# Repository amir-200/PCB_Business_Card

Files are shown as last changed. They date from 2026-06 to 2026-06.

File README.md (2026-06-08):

# PCB_Business_Card

## Final requirements 

1. LED Matrix
2. Battery powered
3. PCB Edge USB-C Connector (For programming/ act as MSC (mass storage class) device to update content)
4. MSC(Mass Storage Class) device so the content of the display can be updated easily
5. Fluid Simulation
6. RTC
7. NFC
8. Provision for interfacing an OLED display 

## Technical Specs

1. Double sided 2 layer PCB
2. 252 LEDs (Yellow/ White)
4. TM1640 LED drive controller IC x 2
5. PCB Edge USB-C Connector 
6. RP2350A MCU 
7. ST25TN01K NFC Forum Type 2 Tag IC
8. TP4057 Linear battery charger
9. QMI8658 IMU 
10. External Flash 
11. LIR2032 Coin cell
12. MOQ : 5

## TODO 

[ ] USB circuitry  : Mihir

[ ] battery charging : amir

[ ] Card Controller foundation: RP2350A power, USB data, flash, I2C bus, Motion Wake interrupt, TM1640 control pins, debug/programming support, and optional power-status sensing

## Card Controller Interface Table

| Subsystem | Candidate part | Interface | Controller signals | Current decision |
| --- | --- | --- | --- | --- |
| Program flash and content storage | Winbond W25Q128JVSIQ, 16 MB | Dedicated RP2350A QSPI | QSPI SCLK, SS, SD0-SD3 | Use one flash with a firmware area and MSC-exposed content partition |
| LED matrix | TM1640 x2 | TM1640 two-wire control | Driver A CLK/DIO, Driver B CLK/DIO | 21 x 12 matrix split as top 6 rows and bottom 6 rows |
| RTC | DS3231 candidate | I2C | SDA, SCL | Revisit later; DS3231 is preferred over DS1307 for 3V3 operation |
| IMU | QMI8658 | I2C plus interrupt | SDA, SCL, IMU_INT | Use dedicated Motion Wake interrupt |
| NFC tag | ST25TN01K | I2C if MCU configuration is needed | SDA, SCL, optional interrupt | Keep on shared I2C unless address or datasheet review says otherwise |
| OLED provision | TBD OLED module | SPI preferred | SCLK, MOSI, CS, DC, RESET | Keep as provision/header; do not share this assumption with TM1640 control |
| USB update | PCB edge USB-C | USB 2.0 plus VBUS sense | USB_DP, USB_DM, VBUS_SENSE | USB exposes MSC content partition and powers/charges card |
| Debug and recovery | Pads plus tiny BOOTSEL button | SWD and boot/reset access | SWDIO, SWCLK, RUN pad, GND, 3V3, BOOTSEL button | Low-profile debug pads; one tiny BOOTSEL button |
| Battery status | TBD divider/switch | ADC sense | BATTERY_SENSE | Include power-conscious battery voltage measurement |

## Things to remember while laying out the pcb 

- the internal regulator component placement and the inductor orientation has to be same as the rasbeery pi  official doc
- AOTA-B201610S3R3-101-T this is the recommended inductor that the official docs recommend 
-  

## Collaboration

- Work on short feature branches for each hardware section, for example `feature/card-controller`.
- Only one person should edit the KiCad schematic/PCB files at a time.
- Push branches to GitHub and review changes before merging to `main`.
- Do not commit KiCad lock files, local history, generated DRC/ERC reports, or temporary files.

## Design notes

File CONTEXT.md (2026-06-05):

# PCB Business Card

A battery-powered interactive PCB business card with display, USB, sensing, storage, and expansion features.

## Language

**Card Controller**:
The main MCU that coordinates the card's display, USB content update path, storage, sensing, timekeeping, NFC-related behavior, and expansion interfaces.
_Avoid_: MCU section, microcontroller block, programming chip

**Interface Map**:
The agreed assignment of card subsystems to controller buses, pins, headers, and test points.
_Avoid_: rough wiring, pin guesses, MCU hookup

**Idle Time Display**:
The low-activity display mode where the card shows the current time while resting.
_Avoid_: standby screen, clock mode

**Shake Animation**:
The short motion-triggered display mode where the card runs the fluid simulation after being shaken.
_Avoid_: fun mode, active mode, animation mode

**Motion Wake**:
The IMU interrupt signal that tells the Card Controller to start a Shake Animation.
_Avoid_: shake polling, movement check

**LED Matrix**:
The 21 by 12 rectangular display made from 252 LEDs on one side of the card.
_Avoid_: LEDs, display lights

**Display Map**:
The coordinate and driver ownership map for the LED Matrix.
_Avoid_: LED order, driver split

**Debug Pads**:
Low-profile physical pads that expose Card Controller bring-up and recovery signals without using a visible header.
_Avoid_: debug header, programming connector

**BOOTSEL Button**:
A tiny physical button used to request USB boot mode during Card Controller reset or power-up.
_Avoid_: reset button, dual-purpose button

**Program Flash**:
The external 16 MB QSPI flash that stores the Card Controller firmware and related program data.
_Avoid_: storage flash, memory chip, content storage

**Content Partition**:
The user-editable region of Program Flash exposed over USB mass storage for display content updates.
_Avoid_: files, MSC memory, flash storage

**USB Update Mode**:
The powered-by-USB mode where the Card Controller exposes the Content Partition as a mass storage device.
_Avoid_: programming mode, USB mode

**VBUS Sense**:
A Card Controller input that detects whether USB power is present.
_Avoid_: USB power wire, charger input

**Battery Sense**:
A power-conscious Card Controller measurement of battery voltage for brightness and runtime decisions.
_Avoid_: raw battery pin, battery wire

## Relationships

- The **Card Controller** coordinates the card's display, storage, sensing, timekeeping, NFC-related behavior, and expansion interfaces.
- The **Interface Map** defines how the **Card Controller** connects to the LED drivers, USB data path, storage, sensors, RTC, NFC behavior, OLED provision, power-status sensing, and debug access.
- The **Idle Time Display** uses the RTC and display while keeping power draw low.
- The **Shake Animation** uses IMU motion detection to trigger a short fluid simulation burst before returning to the **Idle Time Display**.
- **Motion Wake** is a dedicated IMU interrupt input to the **Card Controller**, separate from the I2C bus.
- The **LED Matrix** is controlled by two TM1640 LED drivers and is used by both the **Idle Time Display** and **Shake Animation**.
- The **Display Map** splits the **LED Matrix** into a top six rows controlled by one TM1640 and a bottom six rows controlled by the other TM1640.
- **Debug Pads** expose SWD, reset or run control, power reference, and ground for Card Controller bring-up.
- The **BOOTSEL Button** is separate from **Debug Pads** and does not replace reset or SWD recovery access.
- **Program Flash** is connected to the Card Controller through the dedicated QSPI interface.
- The **Content Partition** lives inside **Program Flash** and is exposed by the Card Controller over USB mass storage.
- **USB Update Mode** is entered when USB is connected and uses **VBUS Sense** to distinguish USB-powered behavior from battery behavior.
- **Battery Sense** helps the Card Controller limit LED brightness and Shake Animation behavior when battery voltage is low.

## Example dialogue

> **Dev:** "Should we work on the MCU section next?"
> **Domain expert:** "Yes, but treat it as the **Card Controller**, because its pin and interface choices affect nearly every remaining subsystem."

> **Dev:** "Can I place the controller symbol first and wire as I go?"
> **Domain expert:** "No, define the **Interface Map** first so pin choices do not accidentally block USB, flash, display, debug, or expansion."

> **Dev:** "Should the fluid simulation run all the time?"
> **Domain expert:** "No, the card normally shows the **Idle Time Display** and only runs the **Shake Animation** for a short timed burst after motion."

> **Dev:** "Can firmware just poll the IMU for shake events?"
> **Domain expert:** "No, use **Motion Wake** so shake detection is available without constant I2C polling."

> **Dev:** "Is the display just a pile of LEDs?"
> **Domain expert:** "No, it is a 21 by 12 **LED Matrix**, so routing and firmware need an explicit coordinate map."

> **Dev:** "Can we split the 21 by 12 matrix into left and right driver halves?"
> **Domain expert:** "No, use the **Display Map** because an 11-column half would exceed one TM1640's 128-LED capacity."

> **Dev:** "Can we skip debug access because USB programming exists?"
> **Domain expert:** "No, use **Debug Pads** so first-board bring-up has a recovery path."

> **Dev:** "Can one button act as both reset and BOOTSEL?"
> **Domain expert:** "No, use a tiny **BOOTSEL Button** and keep reset or run control on **Debug Pads**."

> **Dev:** "Can any SPI flash hold the firmware?"
> **Domain expert:** "No, use **Program Flash** that follows the RP2350A reference QSPI expectations."

> **Dev:** "Does the USB mass storage device need a separate storage chip?"
> **Domain expert:** "No, expose a **Content Partition** inside **Program Flash** for user-editable display content."

> **Dev:** "Can firmware just assume USB is present when data lines enumerate?"
> **Domain expert:** "No, add **VBUS Sense** so **USB Update Mode** and battery behavior can be separated cleanly."

> **Dev:** "Can the controller read battery voltage directly?"
> **Domain expert:** "No, use **Battery Sense** so voltage measurement is safe for the Card Controller and does not waste coin-cell current."

## Flagged ambiguities

- "MCU section" was resolved as **Card Controller**, meaning the central controller for all major card behavior rather than only the programming circuitry.

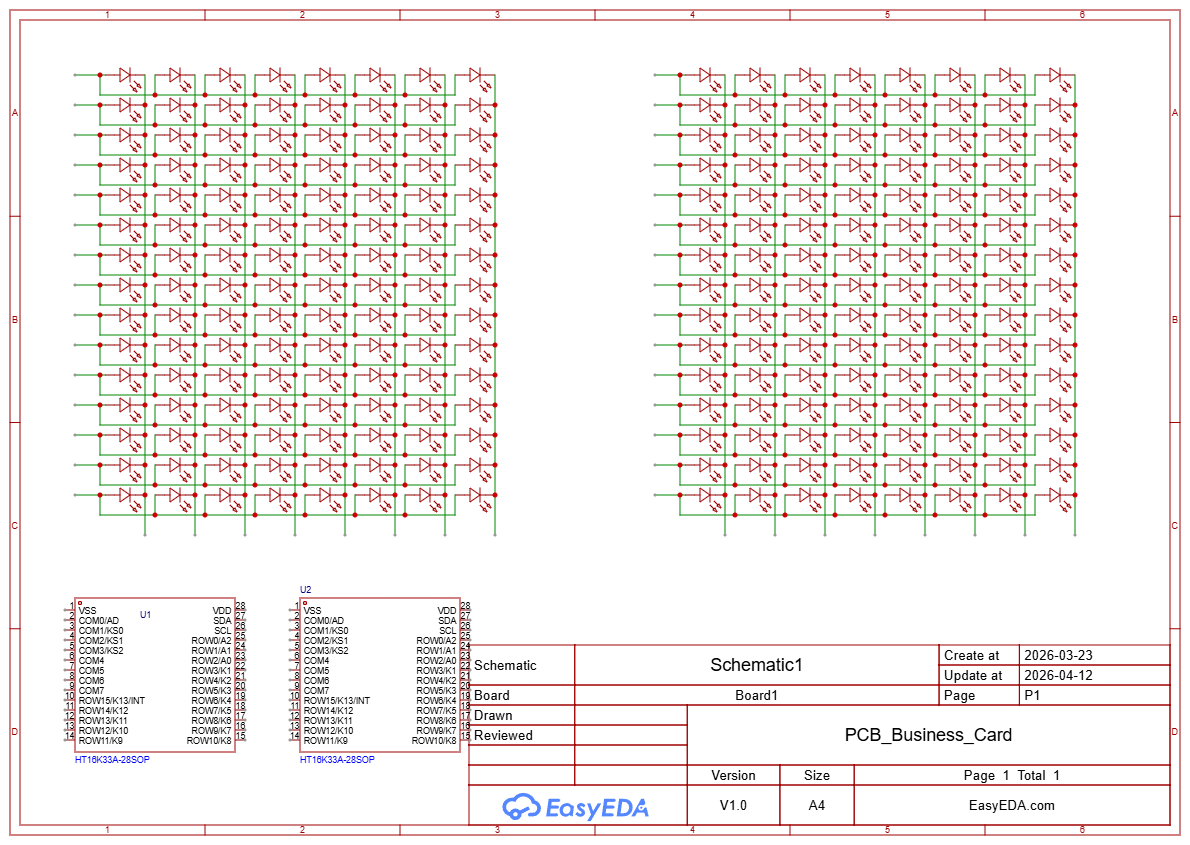
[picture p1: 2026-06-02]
PCB_Business_Card_Schematic1_1-P1_2026-04-12.png

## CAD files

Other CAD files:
PCB_Business_Card_led_placement_drawing.dxf

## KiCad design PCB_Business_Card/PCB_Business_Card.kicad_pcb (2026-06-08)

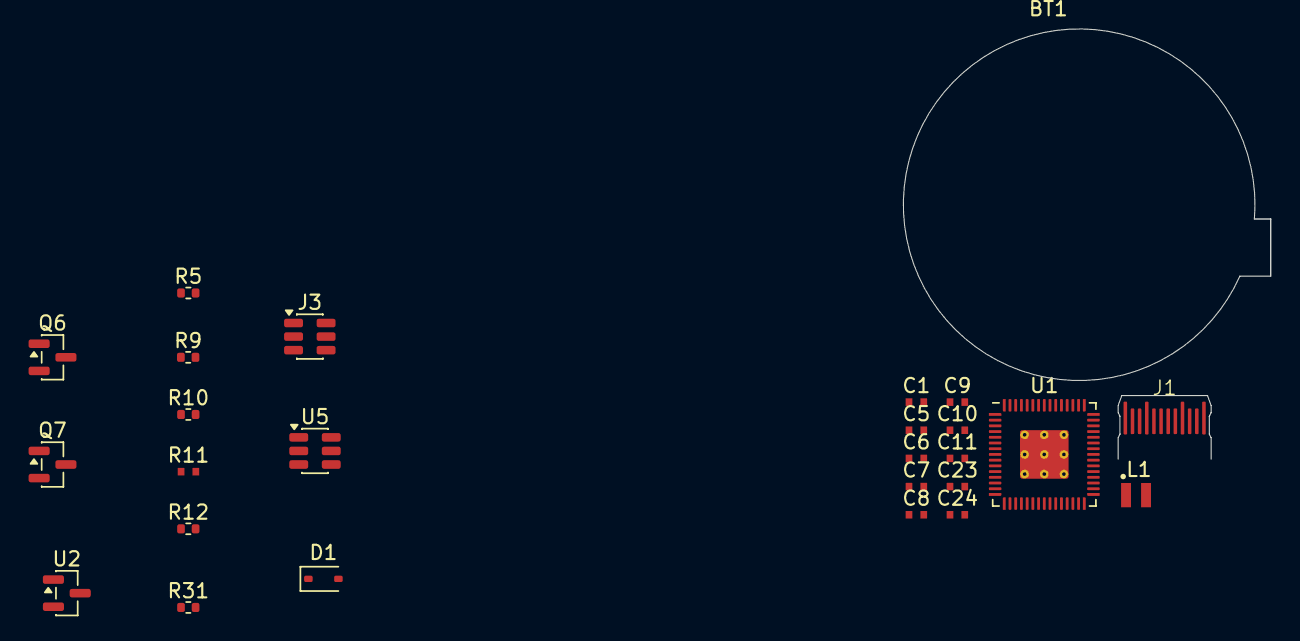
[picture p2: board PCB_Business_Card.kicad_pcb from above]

Board: 2 copper layers, 25.7 x 30.1 mm, 26 parts (0 on the bottom side), 18 nets, no tracks yet.

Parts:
BT1: Battery_Cell; BatteryHolder_Custom
C1, C5, C24: 1u; C_0402_1005Metric_small_pads
C6, C7, C9, C10: 4.7u; C_0402_1005Metric_small_pads
C8, C11, C23: 100n; C_0402_1005Metric_small_pads
D1: Schottky Diode; D_SOD-323
J1: USB_C_Receptacle_USB2.0_14P; USB_C_PADDLE
J3: TP4057; SOT-23-6
L1: 3.3u; L_pol_2016
Q6, Q7: HL-2302V; SOT-23
R5: 33; R_0402_1005Metric
R9: 20K; R_0402_1005Metric
R10: 100; R_0402_1005Metric
R11: 5K1; C_0402_1005Metric_small_pads
R12: 5K1; R_0402_1005Metric
R31: 1K; R_0402_1005Metric
U1: RP2350A; RP2350-QFN-60-1EP_7x7_P0.4mm_EP3.4x3.4mm_ThermalVias
U2: REG_3.3V; SOT-23
U5: DW01A; SOT-23-6

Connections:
+1V1: C7.1, C8.1, C10.1, C11.1, L1.1, U1.6 (DVDD), U1.23 (DVDD), U1.39 (DVDD), U1.50 (VREG_FB)
+3V3: C5.1, C6.1, R5.1, U1.49 (VREG_VIN), U2.2 (VO)
/USB_D+: J1.A6 (D+), J1.B6 (D+)
/USB_D-: J1.A7 (D-), J1.B7 (D-)
/VREG_AVDD: C9.1, R5.2, U1.46 (VREG_AVDD)
/VREG_LX: L1.2, U1.48 (VREG_LX)
GND: C1.2, C5.2, C6.2, C7.2, C8.2, C9.2, C10.2, C11.2, C24.2, J1.A1 (GND), J1.A12 (GND), J1.B1 (GND), J1.B12 (GND), J3.2 (GND), J3.5 (STDBY), Q6.2 (S), R9.2, R11.2, R12.2, R31.1, U1.47 (VREG_PGND), U1.61 (GND), U2.1 (GND)
unnamed: BT1.1 (+), C24.1, D1.2 (A), J3.3 (BAT), R10.1
unnamed: BT1.2 (-), C23.2, Q7.2 (S), U5.6 (GND)
unnamed: J1.A5 (CC1), R11.1
unnamed: J1.B5 (CC2), R12.1
unnamed: J3.6 (PROG), R9.1
unnamed: Q6.3 (D), Q7.3 (D)
unnamed: Q6.1 (G), U5.3 (OC)
unnamed: Q7.1 (G), U5.1 (OD)
unnamed: R31.2, U5.2 (CS)
unnamed: C23.1, R10.2, U5.5 (VCC)
VBUS: C1.1, D1.1 (K), J1.A4 (VBUS), J1.A9 (VBUS), J1.B4 (VBUS), J1.B9 (VBUS), J3.4 (VCC), U2.3 (VI)

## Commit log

2026-06-02 added an empty kicad file
    [PCB_Business_Card.kicad_pcb, PCB_Business_Card.kicad_sch]
2026-06-03 Added USB and power circuitry, updated TP4056 -> TP4057
    [PCB_Business_Card.kicad_sch]
2026-06-05 chore: clean KiCad collaboration setup
2026-06-05 added the datasheet of tm1640 led driver ic and hardware guide of rp2350
2026-06-08 feature progress : ok so i added the decoupling capacitors and the flash memory to the circuit a small part is remaining to complete the mcu section
    [PCB_Business_Card.kicad_pcb, PCB_Business_Card.kicad_sch]
2026-06-10 update: added the neccesary caps and resistors for the flash memory and the flash memory part is completed
    [PCB_Business_Card.kicad_sch]
